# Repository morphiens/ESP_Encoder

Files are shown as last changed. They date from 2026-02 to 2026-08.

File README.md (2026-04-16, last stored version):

# ESP Encoder

A collection of ESP32-based encoder measurement projects using the AS5047D 14-bit magnetic rotary encoder.

Each project lives in `projects/` with its own Python scripts. All projects share firmware templates from `firmware/`.

---

## Firmware Templates

| Template | Location | Use When |
|---|---|---|
| **Single Encoder** | [`firmware/single_encoder/`](firmware/single_encoder/) | One ESP reads one encoder, sends directly to PC via BLE |
| **Dual Encoder** | [`firmware/dual_encoder/`](firmware/dual_encoder/) | One ESP reads two encoders on same SPI bus, sends to PC via BLE |
| **Master** | [`firmware/master/`](firmware/master/) | ESP32C6 — aggregates encoder data from slaves, sends to PC via BLE |
| **Slave** | [`firmware/slave/`](firmware/slave/) | ESP32C3 — reads one encoder, responds to master over ESP-NOW |

### Flashing a Single-Encoder Project

1. Open `firmware/single_encoder/single_encoder.ino` in Arduino IDE
2. Edit the config block at the top:
   ```cpp
   #define ESP_NAME            "YOUR_DEVICE_NAME"
   #define SERVICE_UUID        "4fafc201-..."
   #define CHARACTERISTIC_UUID "beb5483e-..."
   ```
3. Select board (XIAO ESP32C3 or ESP32C6) and upload

### Flashing a Multi-Encoder Project (Master + Slave)

See [`Oliver/README.md`](Oliver/README.md) for full setup instructions.

---

## Projects

| Project | Firmware | Description |
|---|---|---|
| [block_height](projects/block_height/) | Single Encoder | Block height from encoder rotation via trigonometry or polynomial fit |
| [Oliver](Oliver/) | Master + Slave | Wireless multi-encoder system (ESP32C6 master + ESP32C3 slaves) |

---

## Repository Structure

```
Esp_Encoder/
├── firmware/
│   ├── single_encoder/
│   │   └── single_encoder.ino    # Single ESP → BLE to PC
│   ├── dual_encoder/
│   │   └── dual_encoder.ino      # Single ESP reading 2 Encoders → BLE to PC
│   ├── master/
│   │   └── master.ino            # ESP32C6 master — aggregates slaves, sends BLE
│   └── slave/
│       └── slave.ino             # ESP32C3 slave — reads encoder, replies via ESP-NOW
│
├── projects/
│   └── block_height/             # Block height measurement Python scripts
│
├── Oliver/                       # Multi-encoder project (firmware + Python)
│   ├── master/master.ino         # (copy of firmware/master)
│   ├── slave/slave.ino           # (copy of firmware/slave)
│   ├── oliver.py                 # Python API for BLE communication
│   ├── oliver_raw.py             # Raw BLE data script
│   └── README.md
│
├── Datasheets/
│   └── AS5047D.pdf
├── requirements.txt
├── setup.sh
└── README.md
```

---

## How It Works

### Ultra-Precision Sampling Algorithm

All projects use the same AS5047D reading algorithm:

1. **4,096 raw SPI reads**, split into 16 blocks of 256 samples
2. **Robust mean per block** — discard samples > 1.5 LSB from mean, re-average the rest
3. **Median of 16 block means** — rejects any block corrupted by radio bursts
4. **Convert to degrees**: `angle = (counts × 360) / 16384`

### Single-Encoder BLE Data Format

The single encoder uses the **same 7-field format as Oliver master** for protocol compatibility:

```
<packetIdx>|M0:<angle>,<pkt>,<agc>,<mag>,<magl>,<magh>,<cof>
```

Example: `5|M0:1669900,5,38,1823,0,0,0`

| Field | Description |
|---|---|
| `packetIdx` | Global packet counter (increments per READ) |
| `angle` | Encoder angle × 10000 as integer (e.g. `1669900` = 166.9900°) |
| `pkt` | Same as packetIdx (per-encoder index) |
| `agc` | Automatic gain control (0–255) |
| `mag` | CORDIC magnitude (field strength) |
| `magl / magh / cof` | Diagnostic flags (0 or 1) |

**BLE Commands:**

| Command | Description |
|---|---|
| `READ` | Request one on-demand encoder reading |
| `ZERO` | Set current position as zero reference |

### Multi-Encoder (Oliver) BLE Data Format

```
<gateway_idx>|M0:<angle>,<pkt>,<agc>,<mag>,<magl>,<magh>,<cof>|S0:...|S1:...
```

See [`Oliver/README.md`](Oliver/README.md) for full protocol details.

---

## Getting Started

```bash
./setup.sh
source .venv/bin/activate
```

## License

MIT

---

**Author:** Swaraj Dangare

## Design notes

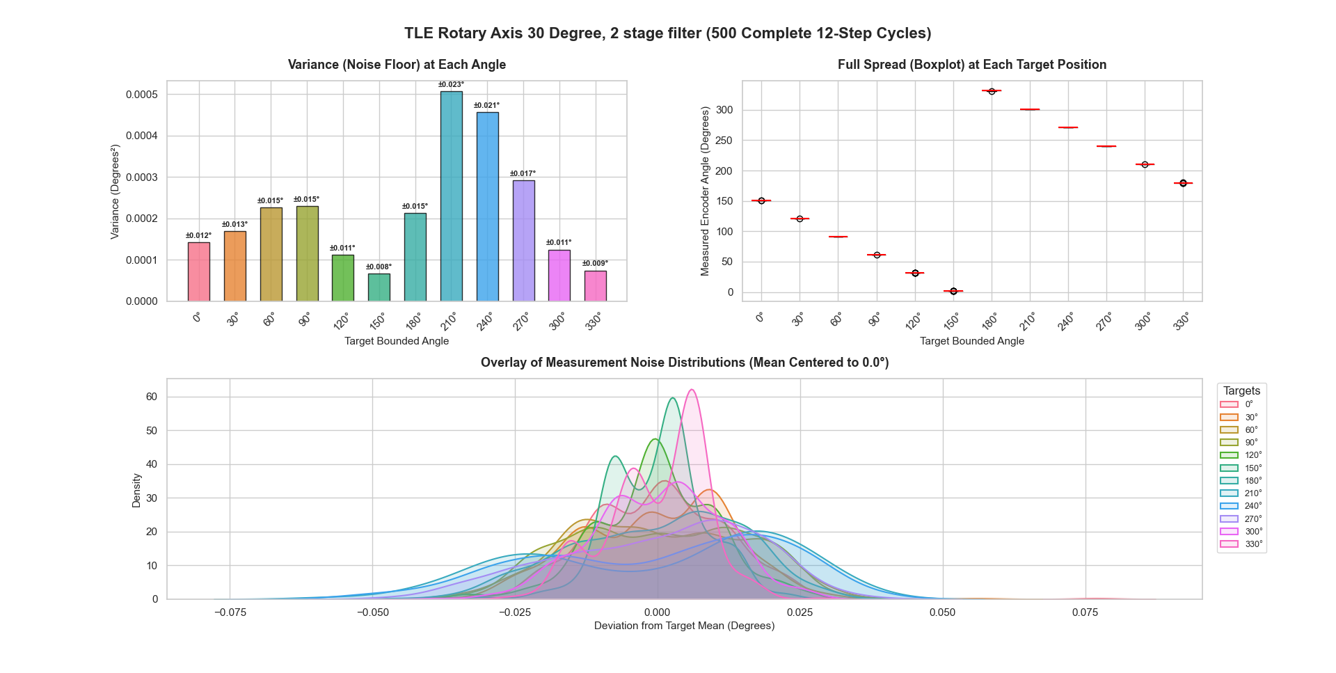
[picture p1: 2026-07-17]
TLE_30_2stage_filter.png

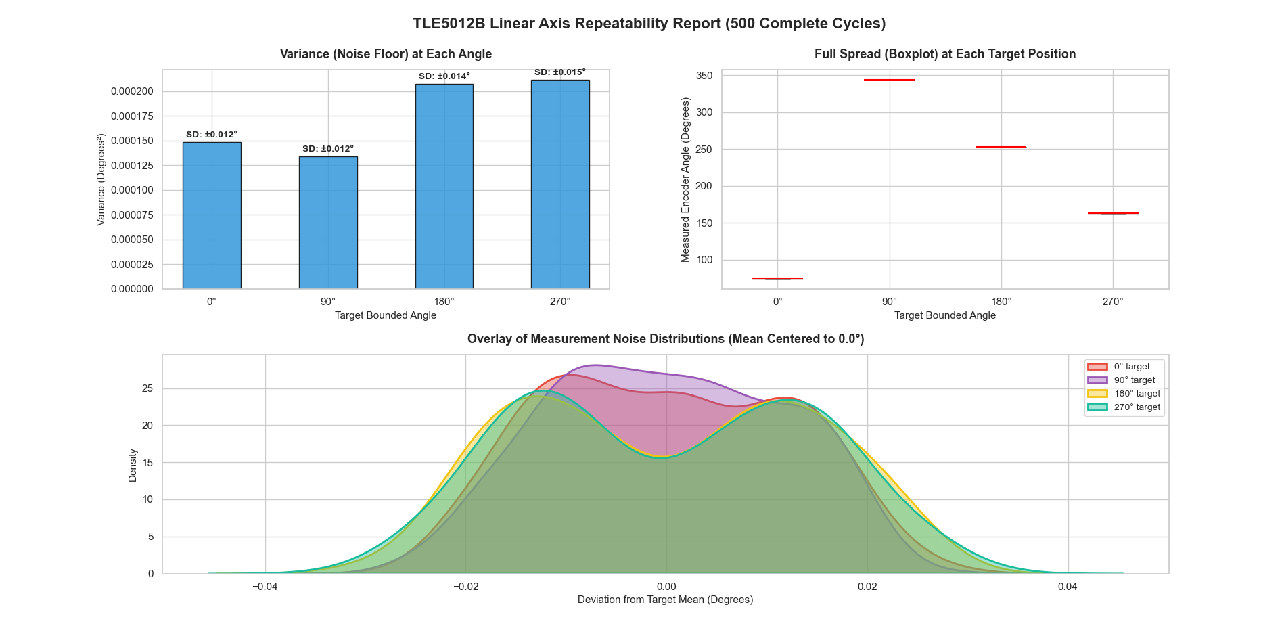
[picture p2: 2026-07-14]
plot_TLE5012B.png

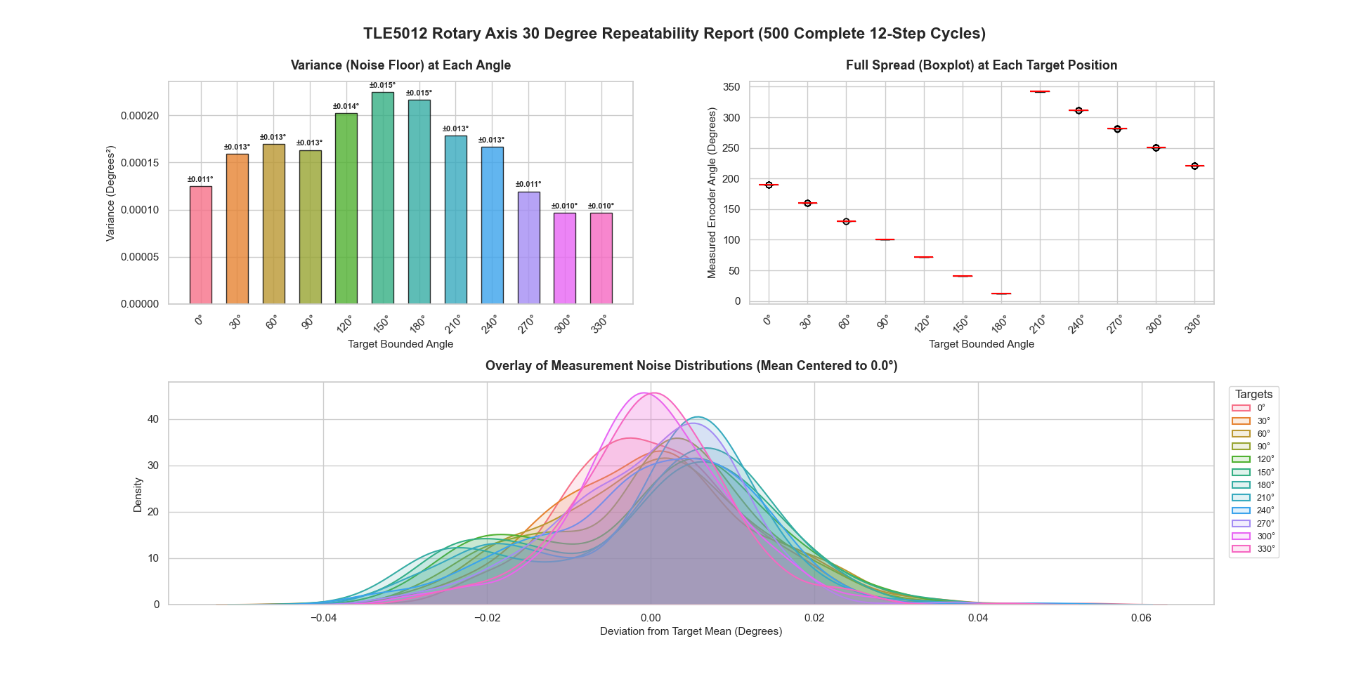
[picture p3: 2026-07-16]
TLE5012_30.png

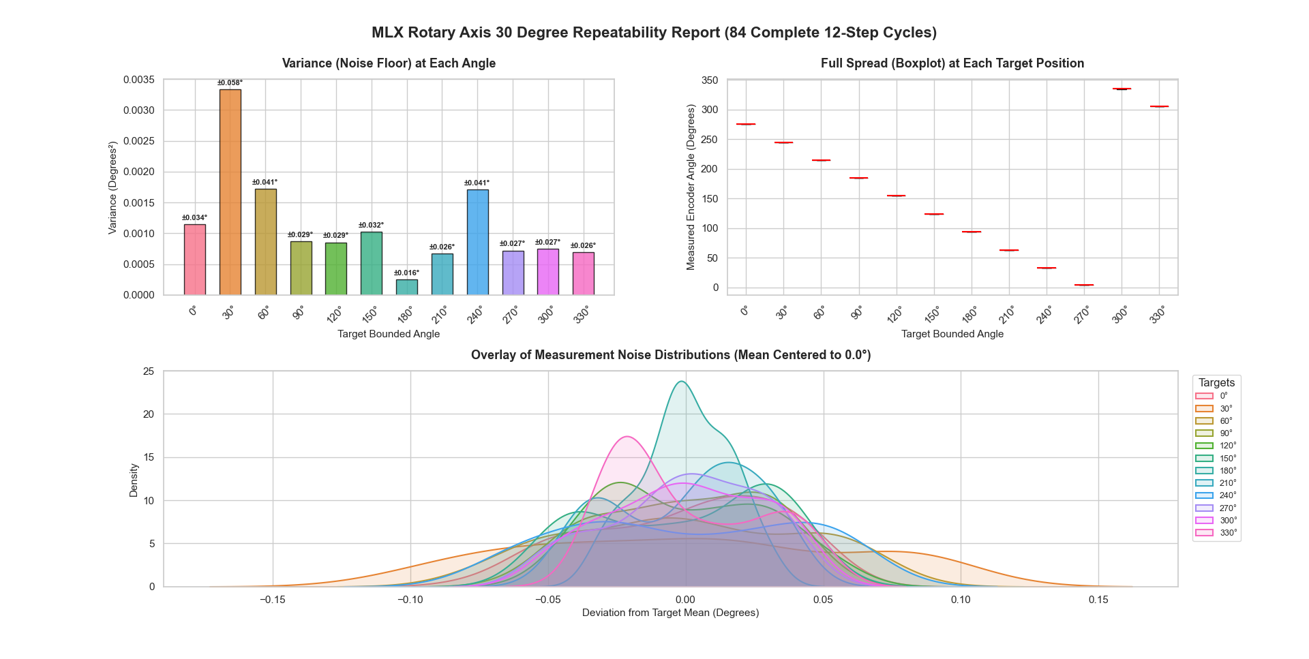
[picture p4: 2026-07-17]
MLX_30.png

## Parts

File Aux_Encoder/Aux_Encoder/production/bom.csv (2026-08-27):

Designator | Footprint | Quantity | Value | LCSC Part #
C14 | 0603 | 1 | 100nF
C15 | 0603 | 1 | 10uF
C16 | 0603 | 1 | 1uF
D11 | TPD1E05U06DPYR | 1 | ESD321DPYR | C436349
D12, D13, D14, D15 | TPD1E05U06DPYR | 4 | TPD1E05U06DPYR | C436349
J4 | JST_SH_SM06B-SRSS-TB_1x06-1MP_P1.00mm_Horizontal | 1 | Conn_01x06_MountingPin
R1 | 0603 | 1 | 22K
R3 | 0603 | 1 | 0K
U1 | IC_AEAT-8800-Q24 | 1 | AEAT-8800-Q24

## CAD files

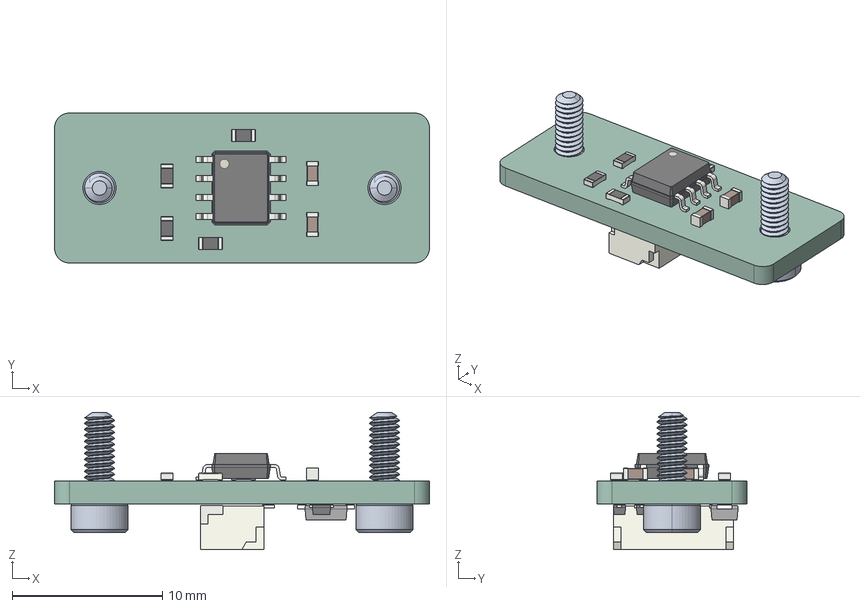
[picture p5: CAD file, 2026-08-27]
Auxiliary_TLE5012B_PCB/TLE5012B_Auxiliary/TLE.step
25.0 x 10.0 x 9.14 mm
R_0603_1608Metric x 4
M2 x 0.4mm Thread 6mm LONG SOCKET HEAD CAP SCREW x 2
C_0603_1608Metric x 2
SOIC-8_3.9x4.9mm_P1.27mm
D_SOD_523 x 4
JST_SH_SM06B-SRSS-TB_1x06-1MP_P1.00mm_Horizontal
D_SMF
TLE5012B_Auxiliary_PCB

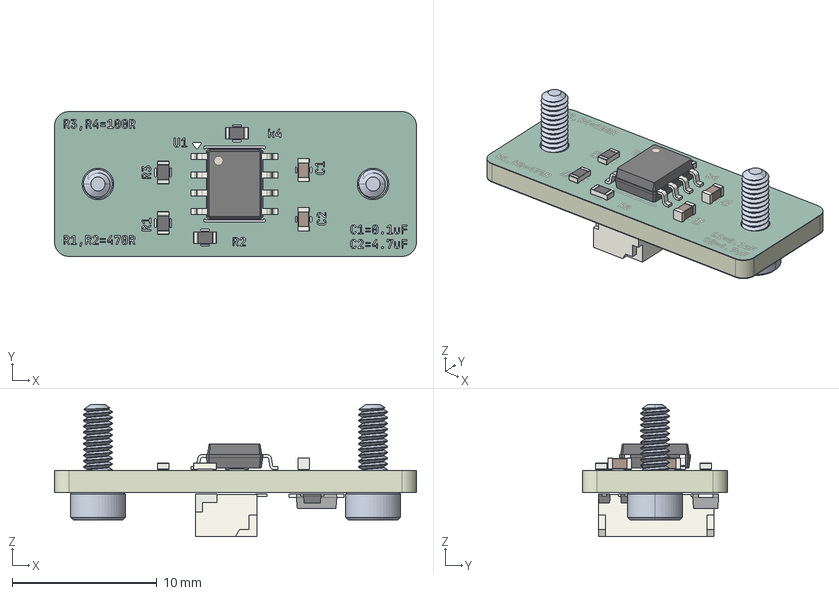
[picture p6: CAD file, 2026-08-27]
Auxiliary_TLE5012B_PCB/TLE5012B_Auxiliary/.TLE_step.step
25.0 x 10.0 x 9.14 mm
R_0603_1608Metric x 4
M2 x 0.4mm Thread 6mm LONG SOCKET HEAD CAP SCREW x 2
C_0603_1608Metric x 2
SOIC-8_3.9x4.9mm_P1.27mm
D_SOD_523 x 4
JST_SH_SM06B-SRSS-TB_1x06-1MP_P1.00mm_Horizontal
D_SMF
TLE5012B_Auxiliary_silkscreen x 2
TLE5012B_Auxiliary_soldermask x 2
TLE5012B_Auxiliary_PCB

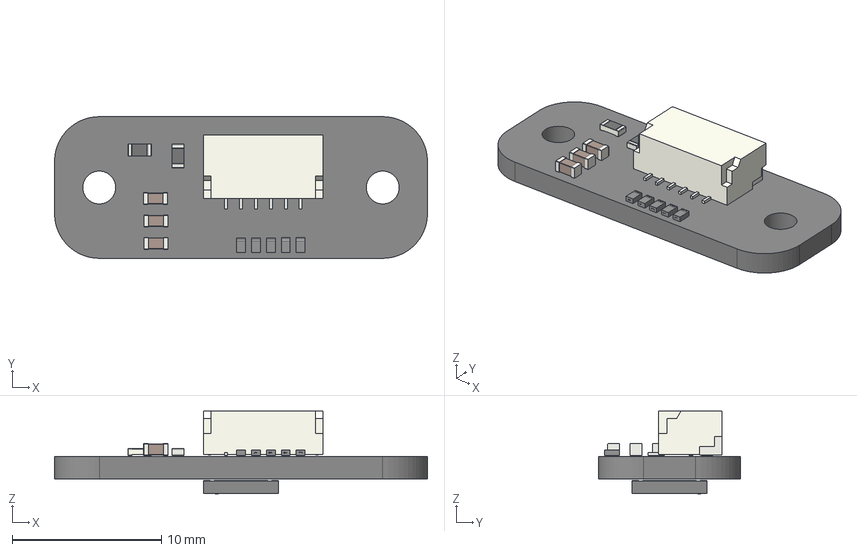
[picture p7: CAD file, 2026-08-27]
Aux_Encoder/Aux_Encoder/4000013854.step
25.0 x 9.50 x 5.53 mm
C_0603_1608Metric x 3
X1SON-2_L1.0-W0.6-P0.65-RD x 5
R_0603_1608Metric x 2
JST_SH_SM06B-SRSS-TB_1x06-1MP_P1.00mm_Horizontal
Aux_Encoder_PCB

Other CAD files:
NEW_TLE5012_AUX/NEW_TLE_AUX/25x10mm_TLE_Aux.step
Auxiliary_TLE5012B_PCB/TLE5012B_Auxiliary/.step

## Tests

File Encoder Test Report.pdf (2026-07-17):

# Magnetic Position Sensor Report

This report documents the performance evaluation of a precision rotary axis with different encoders, namely MLX90382 (https://www.mouser.in/en/ProductDetail/Melexis/MLX90382LGO-BAA-602-RE) (Hall effect, 16bit res) and TLE5012B (https://www.mouser.in/en/ProductDetail/Infineon-Technologies/TLE5012BE5020XUMA1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) (GMR based, 15bit res)

The algorithm used is same for both sensors, just a Simple Moving Average with 1000 samples. Main goal is to check accuracy, error range(peak to peak error) and repeatability.

## Stepper moves from 0-90-180-270-0, for 500 cycles, values are logged and plotted for both

encoders,

Same test is done but with 30 degree increments too, 0-30-60….330-0.

Variance at each angle, boxplot and Probability Density Function is plotted for all the tests.

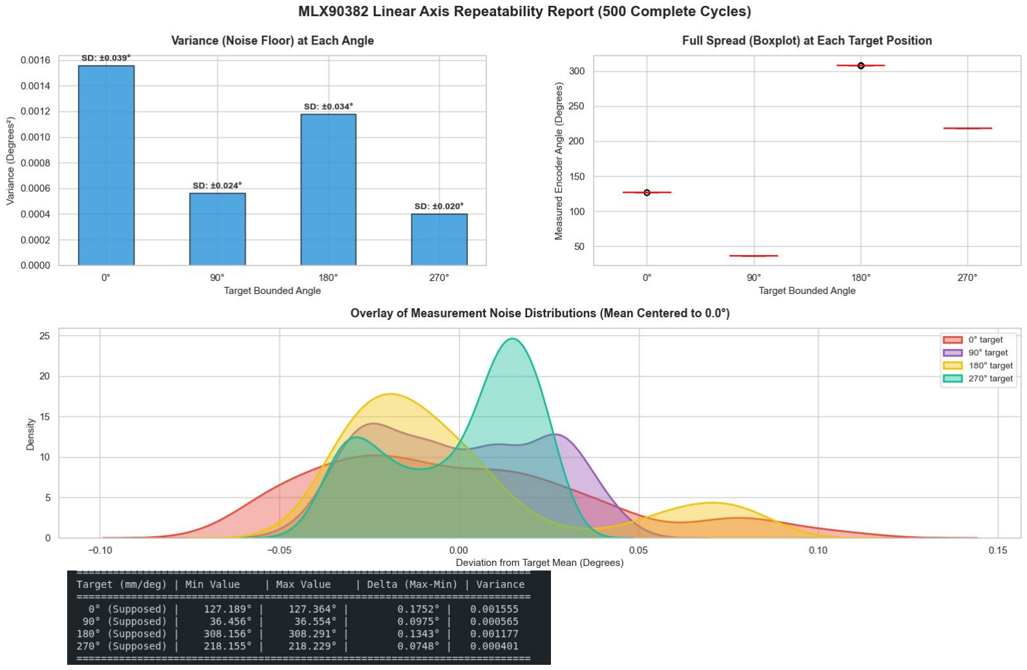
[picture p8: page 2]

### 1. MLX90382 (Hall) 4-Step Sweep

- Results: Repeatability error of 0.075° to 0.175° | Variance of 0.00040 to 0.00155.
- Inference: Mechanical backlash is present. Unequal error at different angles. Mechanical mounting can be better, decent resolution.

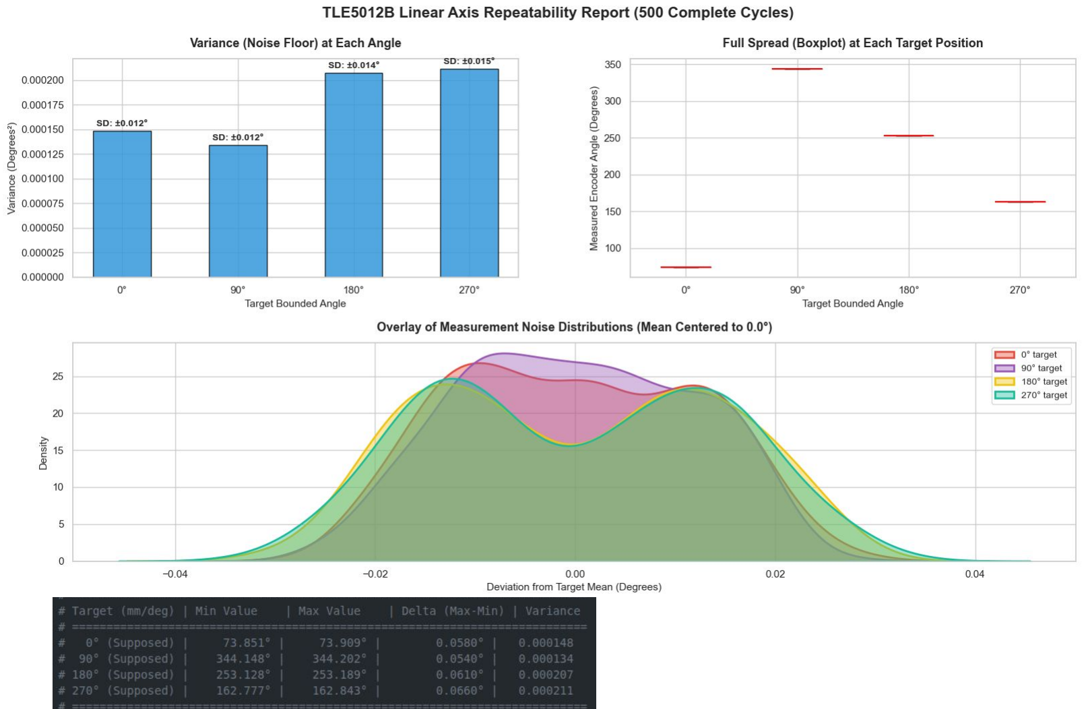
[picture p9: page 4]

### 2. TLE5012B (GMR) 4-Step Sweep

- Results: Repeatability error of 0.054° to 0.066° | Variance of 0.00013 to 0.00021.
- Inference: Incredibly clean and stable. Because GMR is immune to slight mounting offsets, this proves the actual physical backlash is tiny, only ~0.06°.

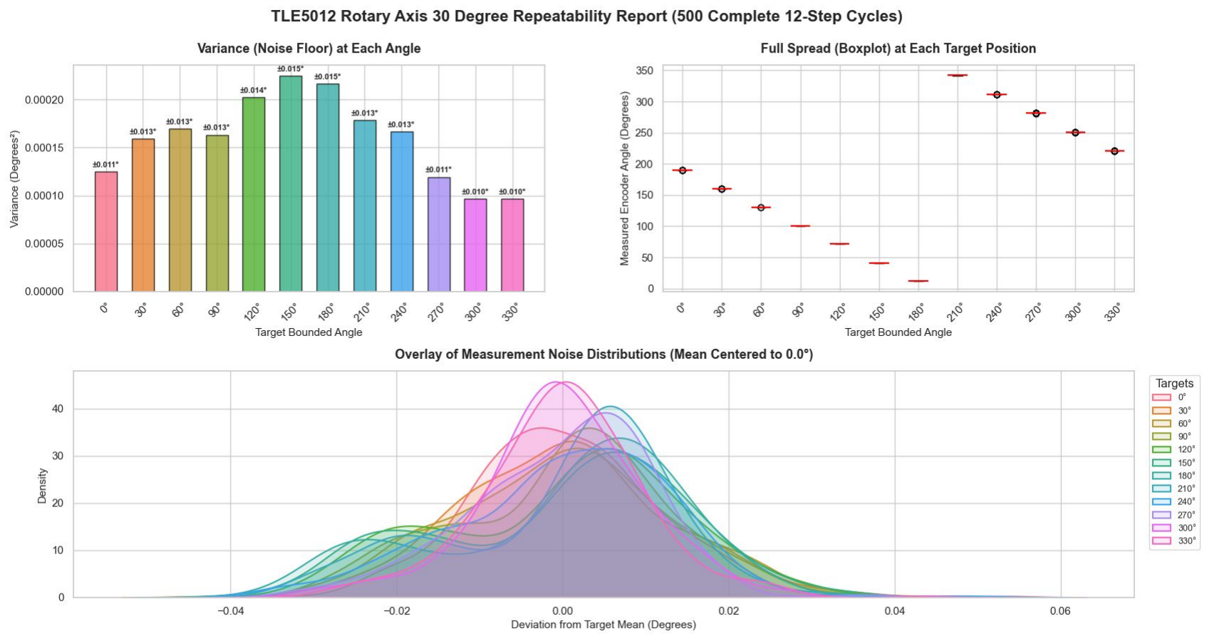
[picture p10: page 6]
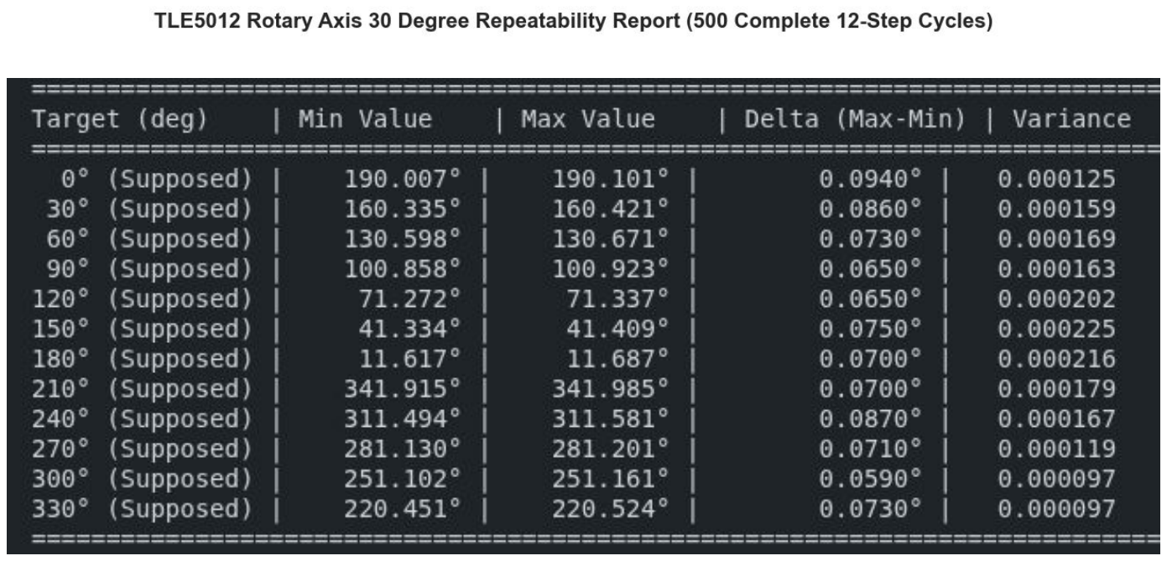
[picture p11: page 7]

### 3. TLE5012B (GMR) — 12-Step Sweep

- Results: Repeatability error of 0.059° to 0.094° | Variance of 0.00009 to 0.00022.
- Inference: Excellent consistency.

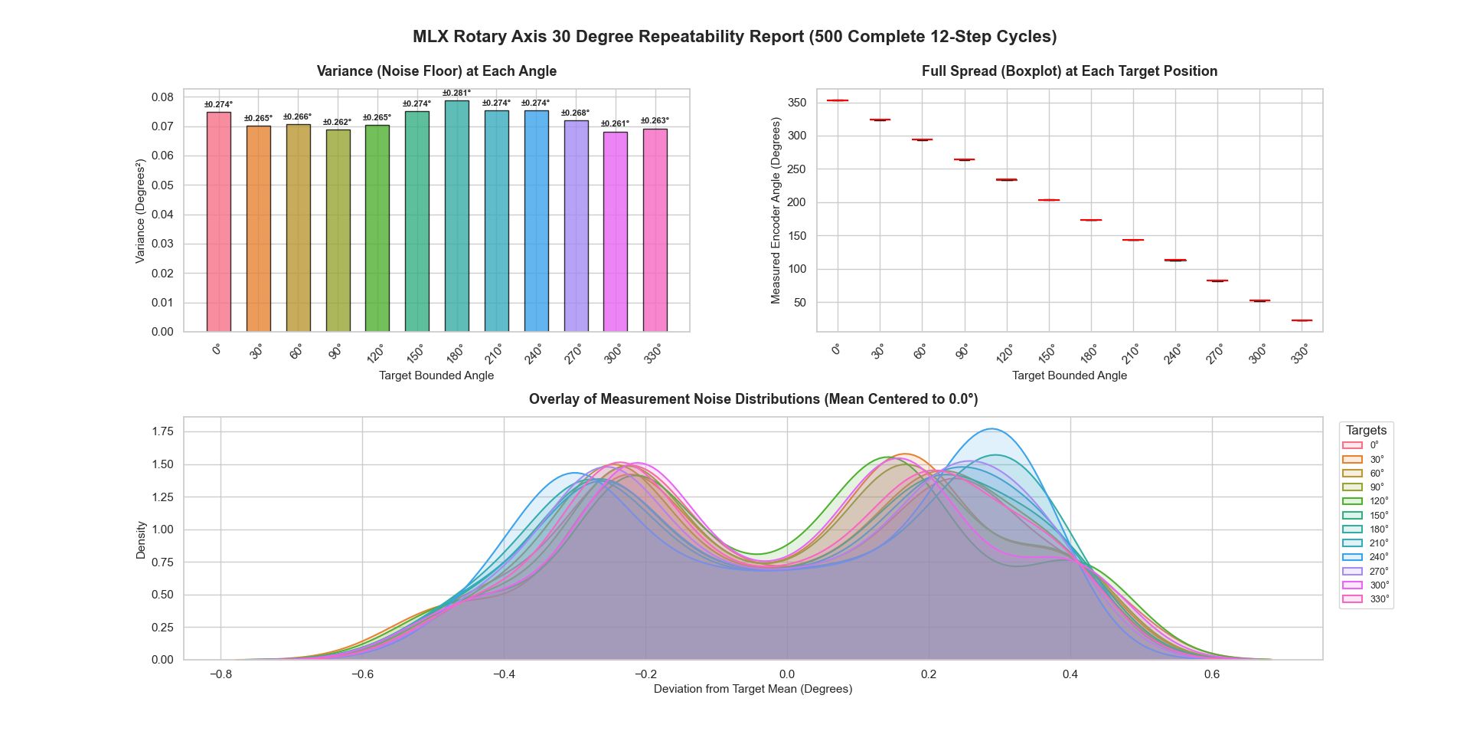
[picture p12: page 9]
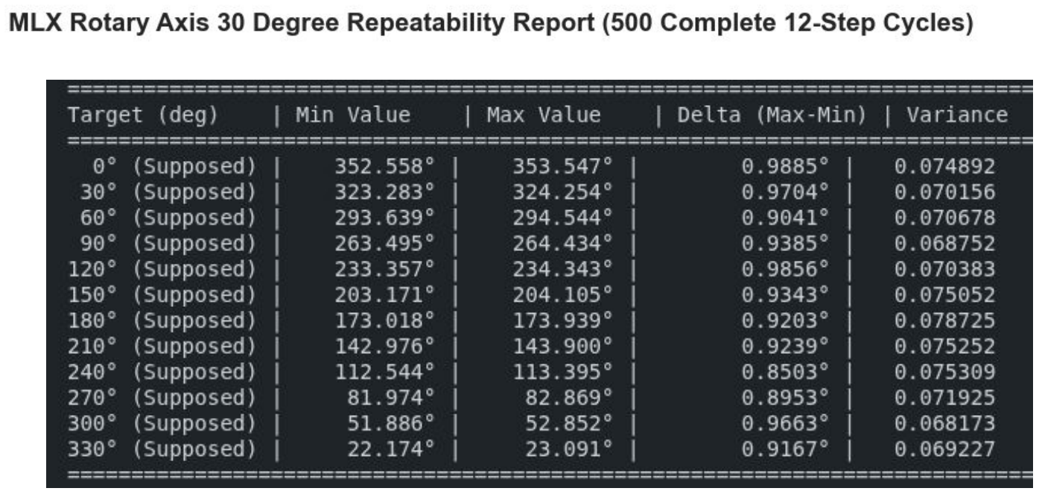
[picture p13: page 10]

### 4. MLX90382 (Hall) — 12-Step Sweep

- Results: Repeatability error of 0.850° to 0.988° (Nearly 1°!) | Variance of 0.068 to 0.078.
- Inference: good PDF, but huge offsets on either side. Variance is higher compared to GMR

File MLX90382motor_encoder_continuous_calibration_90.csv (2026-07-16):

Cycle | Supposed Position | Raw Angle | Filtered Angle | Field Status
1 | 0 | 127.34253 | 127.35504 | 14
1 | 90 | 36.50757 | 36.48258 | 54
1 | 180 | 308.27637 | 308.25742 | 56
1 | 270 | 218.22144 | 218.21313 | 48
2 | 0 | 127.38647 | 127.36295 | 22
2 | 90 | 36.47461 | 36.48908 | 50
2 | 180 | 308.26538 | 308.26019 | 54
2 | 270 | 218.19946 | 218.21875 | 42
3 | 0 | 127.37549 | 127.36404 | 22
3 | 90 | 36.4856 | 36.49439 | 48
3 | 180 | 308.26538 | 308.25693 | 52
3 | 270 | 218.22144 | 218.21396 | 46
4 | 0 | 127.37549 | 127.35724 | 20
4 | 90 | 36.4856 | 36.49342 | 48
4 | 180 | 308.26538 | 308.25708 | 54
4 | 270 | 218.21045 | 218.22124 | 46
5 | 0 | 127.38647 | 127.35847 | 22
5 | 90 | 36.49658 | 36.49299 | 52
5 | 180 | 308.25439 | 308.2558 | 54
5 | 270 | 218.19946 | 218.21883 | 42
6 | 0 | 127.38647 | 127.36156 | 24
6 | 90 | 36.49658 | 36.49755 | 54
6 | 180 | 308.24341 | 308.24982 | 50
6 | 270 | 218.22144 | 218.21584 | 46
7 | 0 | 127.37549 | 127.35782 | 22
7 | 90 | 36.50757 | 36.49068 | 56
7 | 180 | 308.25439 | 308.25046 | 50
7 | 270 | 218.19946 | 218.2253 | 42
8 | 0 | 127.38647 | 127.35935 | 22
8 | 90 | 36.50757 | 36.48936 | 54
8 | 180 | 308.24341 | 308.25378 | 50
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

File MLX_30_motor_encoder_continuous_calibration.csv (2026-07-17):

Cycle | Supposed Position | Raw Angle | Filtered Angle | Field Status
1 | 0 | 352.46338 | 352.55804 | 36
1 | 30 | 323.18481 | 323.28348 | 16
1 | 60 | 293.52173 | 293.64117 | 58
1 | 90 | 263.39722 | 263.49509 | 14
1 | 120 | 233.26172 | 233.3575 | 32
1 | 150 | 203.08228 | 203.1739 | 40
1 | 180 | 172.90283 | 173.01849 | 52
1 | 210 | 142.86621 | 142.97958 | 24
1 | 240 | 112.39014 | 112.54432 | 42
1 | 270 | 81.85913 | 81.97388 | 54
1 | 300 | 51.76758 | 51.88557 | 16
1 | 330 | 22.07153 | 22.17431 | 50
2 | 0 | 352.45239 | 352.58127 | 34
2 | 30 | 323.17383 | 323.28464 | 14
2 | 60 | 293.53271 | 293.6424 | 60
2 | 90 | 263.39722 | 263.50101 | 14
2 | 120 | 233.25073 | 233.36232 | 32
2 | 150 | 203.07129 | 203.17705 | 40
2 | 180 | 172.90283 | 173.0285 | 50
2 | 210 | 142.84424 | 142.98637 | 20
2 | 240 | 112.44507 | 112.54967 | 54
2 | 270 | 81.82617 | 81.97733 | 50
2 | 300 | 51.76758 | 51.89384 | 18
2 | 330 | 22.07153 | 22.18689 | 50
3 | 0 | 352.50732 | 352.59537 | 44
3 | 30 | 323.17383 | 323.29391 | 16
3 | 60 | 293.51074 | 293.6395 | 56
3 | 90 | 263.39722 | 263.49924 | 14
3 | 120 | 233.23975 | 233.36342 | 28
3 | 150 | 203.08228 | 203.17052 | 40
3 | 180 | 172.90283 | 173.02251 | 52
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

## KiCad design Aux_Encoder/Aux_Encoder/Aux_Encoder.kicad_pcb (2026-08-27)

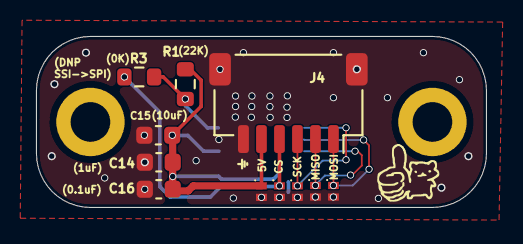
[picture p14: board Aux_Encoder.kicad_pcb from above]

Board: 2 copper layers, 25.0 x 9.5 mm, 14 parts (1 on the bottom side), 7 nets.

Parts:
C14: 100nF; C_0603_1608Metric
C15: 10uF; C_0603_1608Metric
C16: 1uF; C_0603_1608Metric
D11: ESD321DPYR; TPD1E05U06DPYR
D12, D13, D14, D15: TPD1E05U06DPYR
H1, H2: MountingHole; MountingHole_2.2mm_M2_DIN965_Pad
J4: Conn_01x06_MountingPin; JST_SH_SM06B-SRSS-TB_1x06-1MP_P1.00mm_Horizontal
R1: 22K; R_0603_1608Metric
R3: 0K; R_0603_1608Metric
U1: AEAT-8800-Q24; IC_AEAT-8800-Q24

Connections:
+3.3V: C14.1, C15.1, C16.1, D15.1, J4.5, R1.1, U1.14 (VDDA), U1.19 (VDDA)
/CS: D14.1, J4.4, R3.1
/MISO: D12.1, J4.2, U1.12 (SSI_DO_SPI_DO)
/MOSI: D11.1, J4.1, U1.11 (SSI_NSL_SPI_DI)
/SCK: D13.1, J4.3, U1.10 (SSI_SCL_SPI_CLK)
GND: C14.2, C15.2, C16.2, D11.2, D12.2, D13.2, D14.2, D15.2, J4.6, J4.MP (MountPin), U1.13 (VSS), U1.20 (VSS), U1.25 (VSS)
unnamed: R1.2, R3.2, U1.21 (SSI_SPI_SEL)

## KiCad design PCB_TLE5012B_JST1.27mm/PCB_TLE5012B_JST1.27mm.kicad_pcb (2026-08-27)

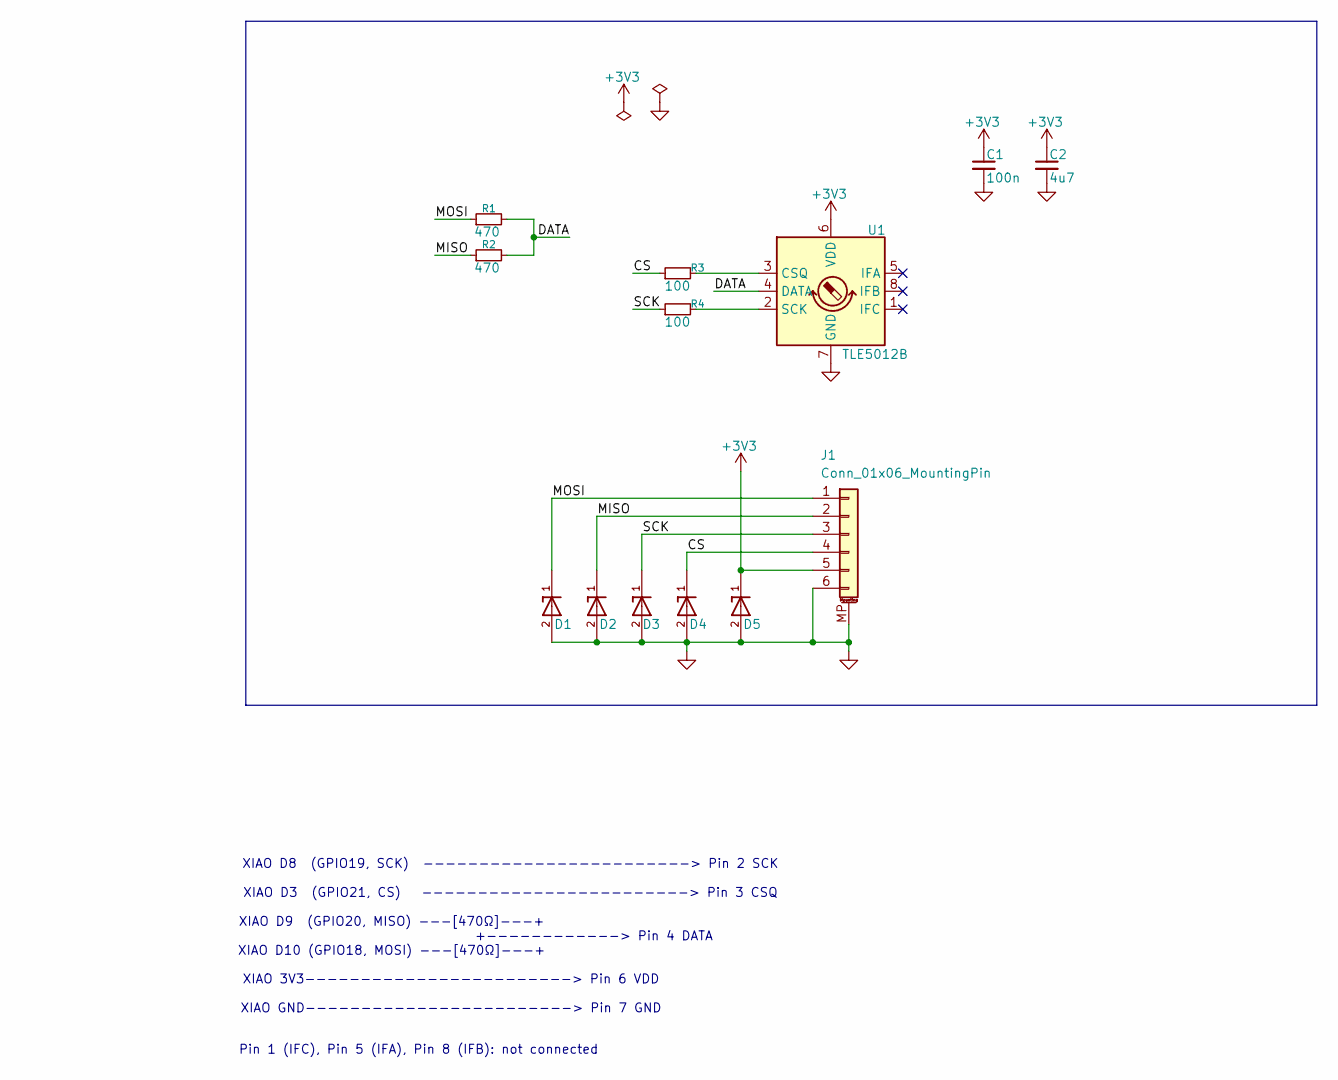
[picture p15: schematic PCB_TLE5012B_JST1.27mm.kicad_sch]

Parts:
C1: 100n; C_0603_1608Metric_Pad1.08x0.95mm_HandSolder
C2: 4u7; C_0603_1608Metric_Pad1.08x0.95mm_HandSolder
D1, D2, D3, D4: TPD1E05U06DPYR; D_SOD-523; PARTREV B
D5: TPD1E05U06DPYR; D_SMF; PARTREV B
J1: Conn_01x06_MountingPin; JST_SH_SM06B-SRSS-TB_1x06-1MP_P1.00mm_Horizontal
R1, R2: 470; R_0603_1608Metric_Pad0.98x0.95mm_HandSolder
R3, R4: 100; R_0603_1608Metric_Pad0.98x0.95mm_HandSolder
U1: TLE5012B; SOIC-8_3.9x4.9mm_P1.27mm

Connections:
+3V3: C1.1, C2.1, D5.1, J1.5, U1.6 (VDD)
/CS: D4.1, J1.4, R3.1
/DATA: R1.2, R2.2, U1.4 (DATA)
/MISO: D2.1, J1.2, R2.1
/MOSI: D1.1, J1.1, R1.1
/SCK: D3.1, J1.3, R4.1
GND: C1.2, C2.2, D1.2, D2.2, D3.2, D4.2, D5.2, J1.6, J1.MP (MountPin), U1.7 (GND)
unnamed: R3.2, U1.3 (CSQ)
unnamed: R4.2, U1.2 (SCK)

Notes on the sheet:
XIAO D9 (GPIO20, MISO) ---[470Ω]---+ +------------> Pin 4 DATA XIAO D10 (GPIO18, MOSI) ---[470Ω]---+
XIAO 3V3------------------------> Pin 6 VDD XIAO GND------------------------> Pin 7 GND
Pin 1 (IFC), Pin 5 (IFA), Pin 8 (IFB): not connected
XIAO D8 (GPIO19, SCK) ------------------------> Pin 2 SCK XIAO D3 (GPIO21, CS) ------------------------> Pin 3 CSQ

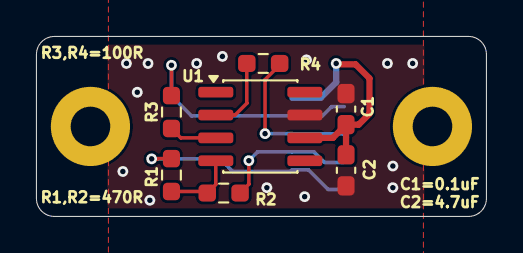
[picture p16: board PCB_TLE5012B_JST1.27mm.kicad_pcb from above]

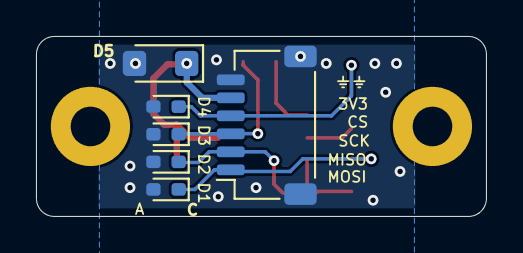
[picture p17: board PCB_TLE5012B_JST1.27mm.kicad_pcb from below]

Board: 2 copper layers, 25.0 x 10.0 mm, 15 parts (6 on the bottom side), 9 nets.

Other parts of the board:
H1, H2: MountingHole; MountingHole_2.2mm_M2_Pad

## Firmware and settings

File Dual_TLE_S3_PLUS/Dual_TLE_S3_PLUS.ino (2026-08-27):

// /*
//  * Dual TLE5012B Hardware SPI Reader (Seeed Studio XIAO ESP32-S3)
//  * Feature: 1000-Sample Circular Vector SMA Filter 
//  * Solution: Eliminates 0/360 degree wraparound glitches completely via Trigonometric Decomposition
//  */

// #include <Arduino.h>
// #include <SPI.h>
// #include <math.h>

// // ==========================================
// // PIN DEFINITIONS (XIAO ESP32-S3 GPIOs)
// // ==========================================
// // SPI Bus 1 (FSPI / SPI2)
// #define SCK1_PIN   7  // D8
// #define MISO1_PIN  8  // D9
// #define MOSI1_PIN  9  // D10
// #define CS1_PIN    4  // D3

// // SPI Bus 2 (HSPI / SPI3)
// #define SCK2_PIN   5  // D4
// #define MISO2_PIN  1  // D0
// #define MOSI2_PIN  6  // D5
// #define CS2_PIN    2  // D1

// const uint16_t CMD_READ_ANGLE = 0x8020; 

// // Hardware SPI settings (4 MHz, Mode 1)
// SPISettings spiSettings(4000000, MSBFIRST, SPI_MODE1);

// // Hardware SPI Instances
// SPIClass spi1(FSPI);
// SPIClass spi2(HSPI);

// // ==========================================
// // VECTOR SMA FILTER (GLITCH-FREE AT 0/360°)
// // ==========================================
// const int SMA_WINDOW = 1000; 

// struct VectorSMA {
//   float sinBuffer[SMA_WINDOW] = {0};
//   float cosBuffer[SMA_WINDOW] = {0};
//   int index = 0;
//   float sinSum = 0;
//   float cosSum = 0;
//   bool full = false;

//   float update(float deg) {
//     // 1. Convert incoming angle to unit vector components
//     float rad = deg * (M_PI / 180.0f);
//     float s = sinf(rad);
//     float c = cosf(rad);

//     // 2. Subtract outgoing sample from running sums
//     if (full) {
//       sinSum -= sinBuffer[index];
//       cosSum -= cosBuffer[index];
//     }

//     // 3. Add new sample to buffers and running sums
//     sinBuffer[index] = s;
//     cosBuffer[index] = c;
//     sinSum += s;
//     cosSum += c;

//     index++;
//     if (index >= SMA_WINDOW) {
//       index = 0;
//       full = true;
//     }

//     // 4. Reconstruct mean vector back to degrees using four-quadrant arctan
//     float avgRad = atan2f(sinSum, cosSum);
//     float avgDeg = avgRad * (180.0f / M_PI);

//     // 5. Wrap safely into positive range [0, 360)
//     if (avgDeg < 0.0f) {
//       avgDeg += 360.0f;
//     }
    
//     return avgDeg;
//   }
// };

// VectorSMA sma1;
// VectorSMA sma2;

// // Output State Variables
// float latestFiltered1 = 0.0f;
// float latestFiltered2 = 0.0f;
// bool enc1Ok = false;
// bool enc2Ok = false;

// static uint32_t lastPrintTime = 0;

// // ==========================================
// // HARDWARE SPI READ FUNCTION
// // ==========================================
// bool readEncoderHW(SPIClass &bus, uint8_t csPin, uint16_t &rawOut) {
//   bus.beginTransaction(spiSettings);
//   digitalWrite(csPin, LOW);
//   delayMicroseconds(1);

//   // Send Read Angle Command
//   bus.transfer16(CMD_READ_ANGLE);

//   // Receive Response
//   uint16_t response = bus.transfer16(0x0000);

//   digitalWrite(csPin, HIGH);
//   bus.endTransaction();

//   // Basic floating bus check
//   if (response == 0x0000 || response == 0xFFFF) {
//     return false;
//   }

//   rawOut = response & 0x7FFF; // Extract 15-bit raw angle value
//   return true;
// }

// // ==========================================
// // UTILITY FUNCTIONS
// // ==========================================
// inline float rawToDegrees(uint16_t raw) {
//   return ((float)raw * 360.0f) / 32768.0f;
// }

// static double normalizeDeg3(double deg) {
//   deg = fmod(deg, 360.0);
//   if (deg < 0.0) deg += 360.0;
//   return round(deg * 1000.0) / 1000.0;
// }

// // ==========================================
// // SETUP
// // ==========================================
// void setup() {
//   Serial.begin(115200);
//   delay(1000);

//   // Chip Select Setup
//   pinMode(CS1_PIN, OUTPUT);
//   pinMode(CS2_PIN, OUTPUT);
//   digitalWrite(CS1_PIN, HIGH);
//   digitalWrite(CS2_PIN, HIGH);

//   // Hardware SPI Bus Initialization
//   spi1.begin(SCK1_PIN, MISO1_PIN, MOSI1_PIN, CS1_PIN);
//   spi2.begin(SCK2_PIN, MISO2_PIN, MOSI2_PIN, CS2_PIN);

//   Serial.println("\n--- Vector SMA (1000 Samples) Dual SPI Ready ---");
// }

// // ==========================================
// // MAIN LOOP
// // ==========================================
// void loop() {
//   uint16_t raw1 = 0;
//   uint16_t raw2 = 0;

//   // 1. HIGH-SPEED BACKGROUND VECTOR FILTERING
//   enc1Ok = readEncoderHW(spi1, CS1_PIN, raw1);
//   if (enc1Ok) {
//     latestFiltered1 = sma1.update(rawToDegrees(raw1));
//   }

//   enc2Ok = readEncoderHW(spi2, CS2_PIN, raw2);
//   if (enc2Ok) {
//     latestFiltered2 = sma2.update(rawToDegrees(raw2));
//   }

//   // 2. SERIAL OUTPUT PRINTING (Every 200ms)
//   if (millis() - lastPrintTime >= 100) {
//     lastPrintTime = millis();

//     if (enc1Ok && enc2Ok) {
//       Serial.printf("ENC1: %.3f deg | ENC2: %.3f deg\n", 
//                     normalizeDeg3(latestFiltered1), 
//                     normalizeDeg3(latestFiltered2));
//     } else if (!enc1Ok && !enc2Ok) {
//       Serial.println("ENC1: ERR | ENC2: ERR");
//     } else if (!enc1Ok) {
//       Serial.printf("ENC1: ERR | ENC2: %.3f deg\n", normalizeDeg3(latestFiltered2));
//     } else {
//       Serial.printf("ENC1: %.3f deg | ENC2: ERR\n", normalizeDeg3(latestFiltered1));
//     }
//   }
// }


/*
 * Dual TLE5012B — XIAO ESP32-S3 Plus (PCB pins)
 * Direction via sensor MOD_2.ANG_DIR (rewritten each boot)
 *
 * Encoder 1 (FSPI): D8/D9/D10/D3
 * Encoder 2 (HSPI): D5/D0/D1/D2
 *
 * true  = Clockwise     (ANG_DIR = 1)
 * false = Counter-CW    (ANG_DIR = 0, factory default)
 */

#include <Arduino.h>
#include <SPI.h>
#include <math.h>

// ========== Direction (change these) ==========
#define ENC1_DIR_CW  false
#define ENC2_DIR_CW  false

// ========== PCB pins ==========

#define SCK1_PIN   D1  // GPIO7
#define MISO1_PIN  D9  // GPIO8
#define MOSI1_PIN  D5  // GPIO9
#define CS1_PIN    D4  // GPIO4

#define SCK2_PIN   D8    // GPIO6
#define MISO2_PIN  D0    // GPIO1
#define MOSI2_PIN  D10   // GPIO2
#define CS2_PIN    D3    // GPIO3

SPIClass spi1(FSPI);
SPIClass spi2(HSPI);

const uint16_t CMD_READ_ANGLE = 0x8020;
// MOD_2 config access: write=0x5081, read=0xD081
const uint16_t CMD_WRITE_MOD2 = 0x5081;
const uint16_t CMD_READ_MOD2  = 0xD081;
const uint16_t MOD2_DEFAULT   = 0x0801;  // 360°, CCW, autocal on
const uint16_t MOD2_ANG_DIR   = 0x0008;  // bit 3

SPISettings spiSettings(1000000, MSBFIRST, SPI_MODE1);

const int SMA_WINDOW = 500;

struct VectorSMA {
  float sinBuffer[SMA_WINDOW] = {0};
  float cosBuffer[SMA_WINDOW] = {0};
  int index = 0;
  float sinSum = 0, cosSum = 0;
  bool full = false;

  float update(float deg) {
    float rad = deg * (M_PI / 180.0f);
    float s = sinf(rad), c = cosf(rad);
    if (full) { sinSum -= sinBuffer[index]; cosSum -= cosBuffer[index]; }
    sinBuffer[index] = s; cosBuffer[index] = c;
    sinSum += s; cosSum += c;
    if (++index >= SMA_WINDOW) { index = 0; full = true; }
    float avgDeg = atan2f(sinSum, cosSum) * (180.0f / M_PI);
    if (avgDeg < 0.0f) avgDeg += 360.0f;
    return avgDeg;
  }
};

VectorSMA sma1, sma2;
float latest1 = 0, latest2 = 0;
bool ok1 = false, ok2 = false;
uint32_t lastPrint = 0;

bool readEncoderHW(SPIClass &bus, uint8_t cs, uint16_t &rawOut) {
  bus.beginTransaction(spiSettings);
  digitalWrite(cs, LOW);
  delayMicroseconds(2);

  bus.transfer16(CMD_READ_ANGLE);
  uint16_t data = bus.transfer16(0x0000);
  bus.transfer16(0x0000);  // safety word

  digitalWrite(cs, HIGH);
  bus.endTransaction();
  delayMicroseconds(5);

  if (data == 0x0000 || data == 0xFFFF) return false;
  rawOut = data & 0x7FFF;
  return true;
}

bool writeMod2(SPIClass &bus, uint8_t cs, uint16_t value) {
  bus.beginTransaction(spiSettings);
  digitalWrite(cs, LOW);
  delayMicroseconds(2);

  bus.transfer16(CMD_WRITE_MOD2);
  bus.transfer16(value);
  uint16_t safety = bus.transfer16(0x0000);

  digitalWrite(cs, HIGH);
  bus.endTransaction();
  delayMicroseconds(5);

  return (safety != 0x0000 && safety != 0xFFFF);
}

bool readMod2(SPIClass &bus, uint8_t cs, uint16_t &value) {
  bus.beginTransaction(spiSettings);
  digitalWrite(cs, LOW);
  delayMicroseconds(2);

  bus.transfer16(CMD_READ_MOD2);
  value = bus.transfer16(0x0000);
  bus.transfer16(0x0000);

  digitalWrite(cs, HIGH);
  bus.endTransaction();
  delayMicroseconds(5);

  return (value != 0x0000 && value != 0xFFFF);
}

// Option 1: set ANG_DIR in MOD_2 (must run every boot)
bool setAngleDirection(SPIClass &bus, uint8_t cs, bool clockwise) {
  uint16_t mod2 = MOD2_DEFAULT;

  // Prefer read-modify-write so other MOD_2 bits stay intact
  uint16_t current = 0;
  if (readMod2(bus, cs, current)) {
    mod2 = current & 0x7FFF;  // drop any status/valid bit if present
  }

  if (clockwise) mod2 |= MOD2_ANG_DIR;
  else           mod2 &= ~MOD2_ANG_DIR;

  if (!writeMod2(bus, cs, mod2)) return false;

  // Verify
  uint16_t check = 0;
  if (!readMod2(bus, cs, check)) return false;
  bool bitSet = (check & MOD2_ANG_DIR) != 0;
  return bitSet == clockwise;
}

inline float rawToDeg(uint16_t raw) {
  return ((float)raw * 360.0f) / 32768.0f;
}

static double norm3(double d) {
  d = fmod(d, 360.0);
  if (d < 0.0) d += 360.0;
  return round(d * 1000.0) / 1000.0;
}

void setup() {
  Serial.begin(115200);
  delay(1000);

  pinMode(CS1_PIN, OUTPUT);
  pinMode(CS2_PIN, OUTPUT);
  digitalWrite(CS1_PIN, HIGH);
  digitalWrite(CS2_PIN, HIGH);

  spi1.begin(SCK1_PIN, MISO1_PIN, MOSI1_PIN, CS1_PIN);
  spi2.begin(SCK2_PIN, MISO2_PIN, MOSI2_PIN, CS2_PIN);

  delay(5);  // let sensors settle after power-up

  bool d1 = setAngleDirection(spi1, CS1_PIN, ENC1_DIR_CW);
  bool d2 = setAngleDirection(spi2, CS2_PIN, ENC2_DIR_CW);

  Serial.println("--- Dual SPI + ANG_DIR Ready ---");
  Serial.printf("ENC1 DIR: %s (%s)\n",
                ENC1_DIR_CW ? "CW" : "CCW", d1 ? "OK" : "WRITE FAIL");
  Serial.printf("ENC2 DIR: %s (%s)\n",
                ENC2_DIR_CW ? "CW" : "CCW", d2 ? "OK" : "WRITE FAIL");
}

void loop() {
  uint16_t r1 = 0, r2 = 0;

  ok1 = readEncoderHW(spi1, CS1_PIN, r1);
  if (ok1) latest1 = sma1.update(rawToDeg(r1));

  ok2 = readEncoderHW(spi2, CS2_PIN, r2);
  if (ok2) latest2 = sma2.update(rawToDeg(r2));

  if (millis() - lastPrint >= 100) {
    lastPrint = millis();

    if (ok1 && ok2) {
      Serial.printf("ENC1: %.3f deg | ENC2: %.3f deg\n",
                    norm3(latest1), norm3(latest2));
    } else if (!ok1 && !ok2) {
      Serial.println("ENC1: ERR | ENC2: ERR");
    } else if (!ok1) {
      Serial.printf("ENC1: ERR | ENC2: %.3f deg\n", norm3(latest2));
    } else {
      Serial.printf("ENC1: %.3f deg | ENC2: ERR\n", norm3(latest1));
    }
  }
}

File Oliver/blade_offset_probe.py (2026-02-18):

"""
Oliver Encoder API
==================
Clean async API for reading encoder values from the Oliver BLE gateway.

Usage:
    import asyncio
    from blade_offset_probe import OliverAPI

    async def main():
        probe = OliverAPI()
        await probe.connect()

        # Request a fresh encoder reading on-demand; (M0_deg, S0_deg)
        m0, s0 = await probe.get_instantaneous_encoder_values()

        # Take a precision measurement (collects 5 samples); returns (M0_median, S0_median)
        m0_med, s0_med = await probe.get_encoder_values()

        # Set current position as zero reference
        probe.set_zero()

        # Take another measurement (now relative to zero)
        result = await probe.measure()

        # Disconnect cleanly
        await probe.disconnect()

    asyncio.run(main())
"""

import asyncio
import time
import logging
import numpy as np
from dataclasses import dataclass, field
from typing import Optional
from bleak import BleakClient, BleakScanner

# Set False to disable all prints and debug/info logging for the entire file.
VERBOSE = True

# ── Logging ──────────────────────────────────────────────────────────────────
logger = logging.getLogger("oliver")
logger.setLevel(logging.DEBUG if VERBOSE else logging.WARNING)

# ── BLE identifiers ─────────────────────────────────────────────────────────
DEVICE_NAME = "Oliver_3"
CHARACTERISTIC_UUID = "1d4cd358-172d-4c33-b0b2-ddce9a071aab"
COMMAND_UUID = "308a0c43-80f0-4b01-81e5-bb2798eb92f9"

ENCODERS = ("M0", "S0")
SCAN_TIMEOUT_S = 15.0
MEASURE_TIMEOUT_S = 30.0
SAMPLES_PER_MEASUREMENT = 5
REACH_MM = 183.0  # lever arm for µm precision calc


# ── Data classes ─────────────────────────────────────────────────────────────
@dataclass
class EncoderReading:
    """Single encoder snapshot."""
    name: str
    angle_deg: float
    raw_angle_deg: float
    pkt: int = 0
    agc: int = 0
    mag: int = 0
    status: str = "OK"


@dataclass
class MeasurementResult:
    """Result of a multi-sample precision measurement."""
    measurement_id: int
    encoders: dict = field(default_factory=dict)
    timestamp: float = 0.0

    # Per-encoder nested data
    # encoders = {
    #     "M0": {"samples": [...], "median": float, "jitter": float, "precision_um": float, "status": str},
    #     "S0": { ... },
    # }


# ── Packet parser ────────────────────────────────────────────────────────────
def _parse_encoder_field(part: str, gateway_idx: int) -> tuple[str, Optional[tuple[float, dict]]]:
    """
    Parse a single encoder field from the BLE payload.
    Format: 'XX:angle,pkt[,agc,mag,magl,magh,cof]'
    Returns (name, None) for OFFLINE encoders.
    Returns (name, (angle_deg, metadata_dict)) on success.
    """
    name_str, data = part.split(":")
    fields = data.split(",")

    if fields[0] == "OFFLINE":
        return name_str, None

    angle = float(fields[0]) / 10000.0
    pkt = int(fields[1]) if len(fields) > 1 else 0

    if len(fields) >= 7:
        agc, mag = int(fields[2]), int(fields[3])
        magl, magh, cof = fields[4], fields[5], fields[6]
    else:
        agc, mag, magl, magh, cof = 0, 0, "0", "0", "0"

    status = "OK"
    if cof == "1":
        status = "CORDIC_ERR"
    elif magl == "1":
        status = "FIELD_LOW"
    elif magh == "1":
        status = "FIELD_HIGH"

    meta = {
        "g_idx": gateway_idx, "pkt": pkt, "agc": agc, "mag": mag,
        "magl": magl, "magh": magh, "cof": cof, "status": status,
    }
    return name_str, (angle, meta)


# ── Main API class ───────────────────────────────────────────────────────────
class OliverAPI:
    """
    Async API for the Oliver BLE encoder gateway.

    All public methods are safe to call from any async context.
    The object manages its own BLE connection lifecycle.
    """

    def __init__(self):
        # Connection state
        self._client: Optional[BleakClient] = None
        self._device = None
        self._connected = False

        # Live encoder data (updated on every BLE notification)
        self._latest_raw: dict[str, Optional[float]] = {e: None for e in ENCODERS}
        self._latest_meta: dict[str, dict] = {e: {} for e in ENCODERS}
        self._last_gateway_idx = -1
        self._missed_packets = 0
        self._last_notify_time: float = 0.0

        # Notification event (set on every _on_notify, used for on-demand reads)
        self._notify_received: asyncio.Event = asyncio.Event()

        # Zero offsets
        self._zero_offsets: dict[str, float] = {e: 0.0 for e in ENCODERS}

        # Measurement collection state
        self._measurement_id = 0
        self._collecting = False
        self._collect_samples: dict[str, list[float]] = {e: [] for e in ENCODERS}
        self._collect_meta: dict[str, list[dict]] = {e: [] for e in ENCODERS}
        self._collect_done: Optional[asyncio.Event] = None

        # Timing (seconds) of last connect and last get_encoder_values / get_instantaneous call
        self._last_connect_time_s: float = 0.0
        self._last_get_encoder_values_time_s: float = 0.0
        self._last_get_instantaneous_encoder_values_time_s: float = 0.0

    # ── Properties ───────────────────────────────────────────────────────

    @property
    def is_connected(self) -> bool:
        """True when BLE link is active."""
        return self._connected and self._client is not None and self._client.is_connected

    @property
    def missed_packets(self) -> int:
        return self._missed_packets

    @property
    def last_gateway_idx(self) -> int:
        return self._last_gateway_idx

    @property
    def last_connect_time_s(self) -> float:
        """Time in seconds taken by the last connect() (or reconnect()) that did a full connect."""
        return self._last_connect_time_s

    @property
    def last_get_encoder_values_time_s(self) -> float:
        """Time in seconds taken by the last get_encoder_values() call from start to return."""
        return self._last_get_encoder_values_time_s

    @property
    def last_get_instantaneous_encoder_values_time_s(self) -> float:
        """Time in seconds taken by the last get_instantaneous_encoder_values() call from start to return."""
        return self._last_get_instantaneous_encoder_values_time_s

    # ── Connect / Disconnect / Reconnect ─────────────────────────────────

    async def connect(self, timeout: float = SCAN_TIMEOUT_S) -> bool:
        """
        Scan for the gateway and connect.
        Returns True on success, False if the device was not found.
        """
        if self.is_connected:
            logger.info("Already connected.")
            return True

        t0 = time.perf_counter()
        logger.info("Scanning for %s …", DEVICE_NAME)
        self._device = await BleakScanner.find_device_by_filter(
            lambda d, _ad: d.name == DEVICE_NAME, timeout=timeout,
        )
        if self._device is None:
            logger.error("Gateway not found (scanned for %.0fs).", timeout)
            return False
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

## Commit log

2026-02-16 Add on-demand reading functionality to the Oliver project, enhancing encoder data retrieval. Updated README.md with detailed on-demand data flow and encoder angle calculation. Added .venv to .gitigno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
2026-02-19 feat: align single_encoder protocol with Oliver master
    firmware/single_encoder/single_encoder.ino:
    - Switch from continuous to on-demand trigger (PC writes "READ" to fire a reading)
    - Rename zero command: "Z" → "ZERO"
    - Change angle representation: float string → integer × 10000
    - Add global packetIdx counter (increments on each READ)
    - Adopt Oliver-compatible pipe-delimited BLE message format:
    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
2026-04-16 [Swaraj] add BLE firmware for dual AS5047D magnetic encoders on ESP32
2026-04-16 [Swaraj] added readme for dual encoder.ino
2026-05-17 [Swaraj]Add unified firmware for XIAO ESP32-C6 in the Oliver cluster. Introduced BLE setup mode, runtime modes (master, slave, standalone), and ESP-NOW communication. Added README.md with detailed in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
2026-05-21 Update CS and SPI pin assignments for encoders
2026-05-27 [Krishna] 14 bit encoder test
    [Encoder_PCB.step, Encoder_PCB_corrected.f3d, Encoder_PCB_spi_Changed.f3d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]
2026-07-14 [Krishna] TLE5012B Codes added
    [Encoder_PCB.step, Encoder_PCB_corrected.f3d, Encoder_PCB_spi_Changed.f3d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]
2026-07-14 [Krishna] Added logs and repeatability cycle plot
    [motor_encoder_continuous_calibration.csv]
2026-07-16 [Krishna] Added repeatability test results for 90 and 30 degree
    [MLX90382motor_encoder_continuous_calibration_90.csv, TLE5012Bmotor_encoder_continuous_calibration_90.csv, motor_encoder_continuous_calibration.csv]
2026-07-17 [Krishna] added TLE's 2 stage filter data logs and results
    [MLX_30_motor_encoder_continuous_calibration.csv, TLE_2Stage_motor_encoder.csv, TLE_30_motor_encoder_continuous_calibration.csv]
2026-08-07 Refactor TLE5012B command definitions and status reading logic for improved clarity. Updated CMD_READ_STATUS to CMD_READ_STAT and added detailed comments on magnet diagnostics. Adjusted field status 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
2026-08-27 [krishna] added pcb files and some test codes
    [.TLE_step.step, .step, 25x10mm_TLE_Aux.step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]
2026-09-03 [Krishna] Added TMR validation scritps
    [Failed_TMR_new_reset69_sampling.csv, TMR_90_500cycle.csv, TMR_new_reset500_sampling.csv]
